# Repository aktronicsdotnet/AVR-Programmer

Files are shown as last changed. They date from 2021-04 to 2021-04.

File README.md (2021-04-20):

<b>
AVR Programmer based on USBASP that can be used as a Arduino shield or standalone
</b>
<br><br>
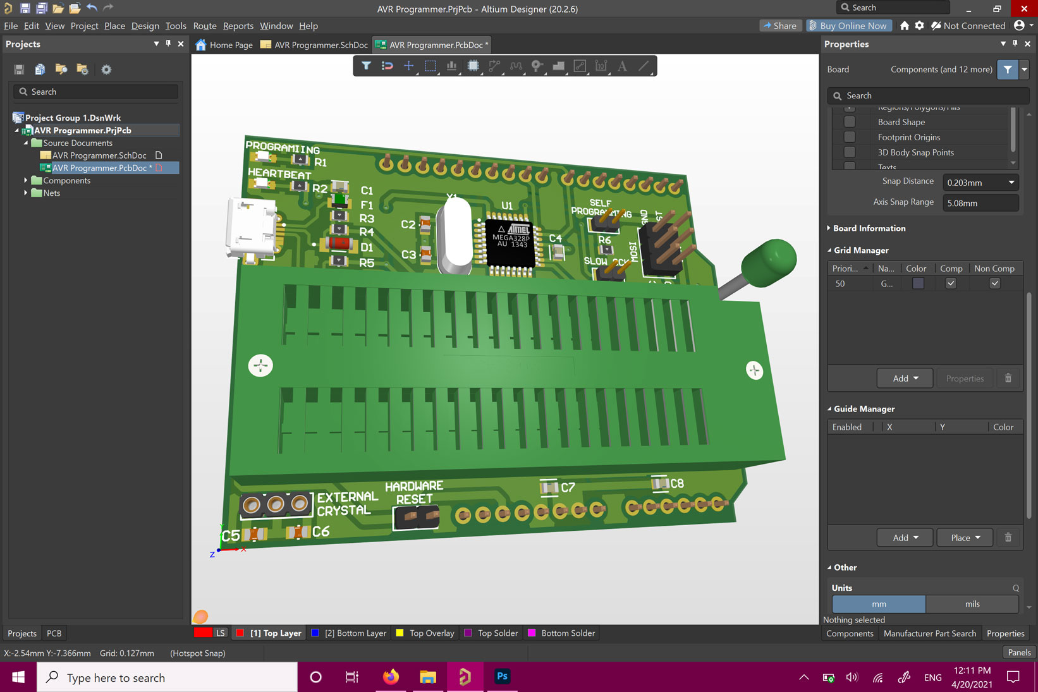
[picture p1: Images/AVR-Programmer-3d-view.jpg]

<br><br>

<b>
What is AVR-Programmer?
</b><br>
Everyone knows that you can use Arduino UNO as a programmer for other AVR MCUs that are supported by Arduino IDE and I'm sure at some point you have heard about USBASP if you have worked with Arduino and AVR MCUs... AVR-Programmer is a combination of these two things and can be used as both of them depending on how you assemble it.
<br><br>

<b>
How to use AVR-Programmer as a shield for Arduino UNO?
</b><br>
This is the easier version; all you need to do is to solder Arduino pin headers (D0 to D13 and power headers) and the ZIF socket. Bam... you are done and now you can upload the AVR as ISP sketch in Arduino ide, plug the shield and use it to program different type of AVR MCUs. Optionally you can populate the R1 and R2 with their respected LEDS to be able to visually see the progress of programming your MCUs and perhaps populate the external crystal socket, C5 and C6 to use external clocks with your MCUs.
<br><br>

<b>
What can I do with AVR-Programmer as a shield for Arduino UNO?
</b><br>
Well together with an Arduino Uno you can burn the bootloader or even program any AVR MCUs that are supported by Arduino IDE. (Officially or with addon packages)
<br><br>

<b>
How to use AVR-Programmer as standalone USBASP?
</b><br>
To my understanding you need to have one AVR programmer or at least an Arduino UNO to be able to programmer the ATMega8 or ATMega88 on the board as a USBASP first. If you have access to a AVR programmer you can use the 6 pin ISP header on the board to program the main MCU, in this case you can skip the Arduino headers completely but if you want to use an Arduino Uno you will need those headers so you will probably need to solder the whole board. Close the Self Programming jumper when you are programming the on board ATMega MCU, this jumper will connect the U1 RST pin to the rest of Reset pins on the board to be able to put 1 in programming mode just when we need it.
<br><br>

<b>
What can I do with AVR-Programmer as standalone USBASP?
</b><br>
Well in this case you can use the Micro USB port to burn the bootloader or program any AVR MCUs that are supported by USBASP. You can directly plug it on Arduino UNO to burn the bootloader or program them, in this case close the Hardware Reset jumper or you can use this board to program other Arduino boards with the 6 pin ISP connector with the standard pinout. 
<br><br>

<b>
What are those jumpers for?
</b><br>
I think it's really self explanatory but there are 3 jumpers on this board. One is called "Self Programming" this jumper is used to program the on board MCU and its job is to connect U1 RST pin to the rest of RESET pins. Another one is called "Slow SCK" this is used to slow down the clock of SCK pin and the last one is called "Hardware Reset" this is used to connect Arduino UNO's RST Pin to the rest of RESET pins to be able to put Arduino UNO boards into programming mode.
<br><br>

<b>
How can I use this?
</b><br>
First you need to send the Gerber files from Gerber X2 folder to your fav PCB manufacturer and wait until they make the PCB for you and the you need to buy the necessary components according to the bill of material and when everything arrived careful solder them to the PCB and use it.
<br><br>

<b>
For more advanced users...
</b><br>
For more advanced users, I've left the original design so you can change anything you want. This board was designed by Altium Designer V20.
<br><br>

<b>
How can you find me?
</b><br>
I will leave my Instagram on this GitHub just in case you needed to contact me for any reason... Instagram @ skopusdotorg
<br><br>

<b>
More pictures?
</b><br>
Here are some more pictures for your visual pleasure I guess...
<br>
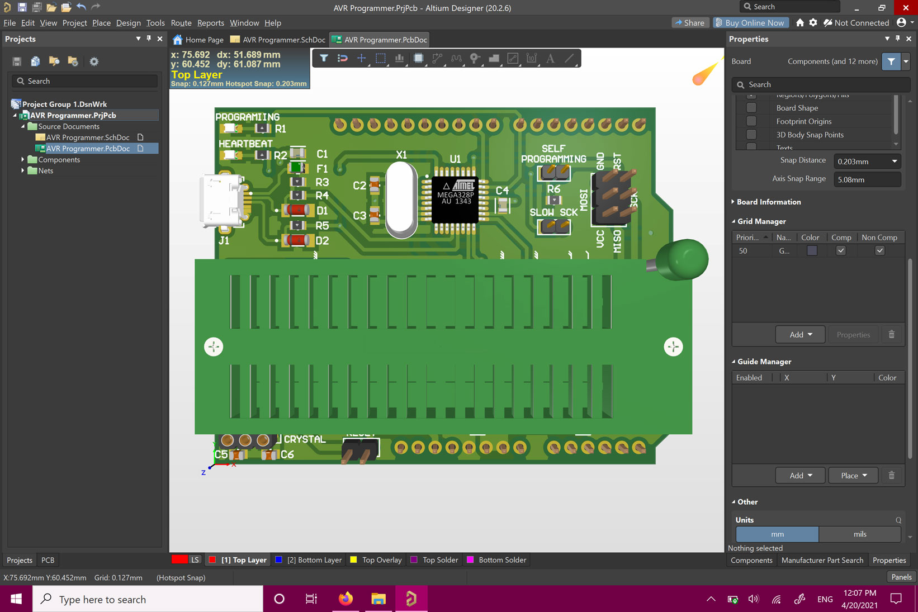
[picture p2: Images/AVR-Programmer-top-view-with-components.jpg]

<br>
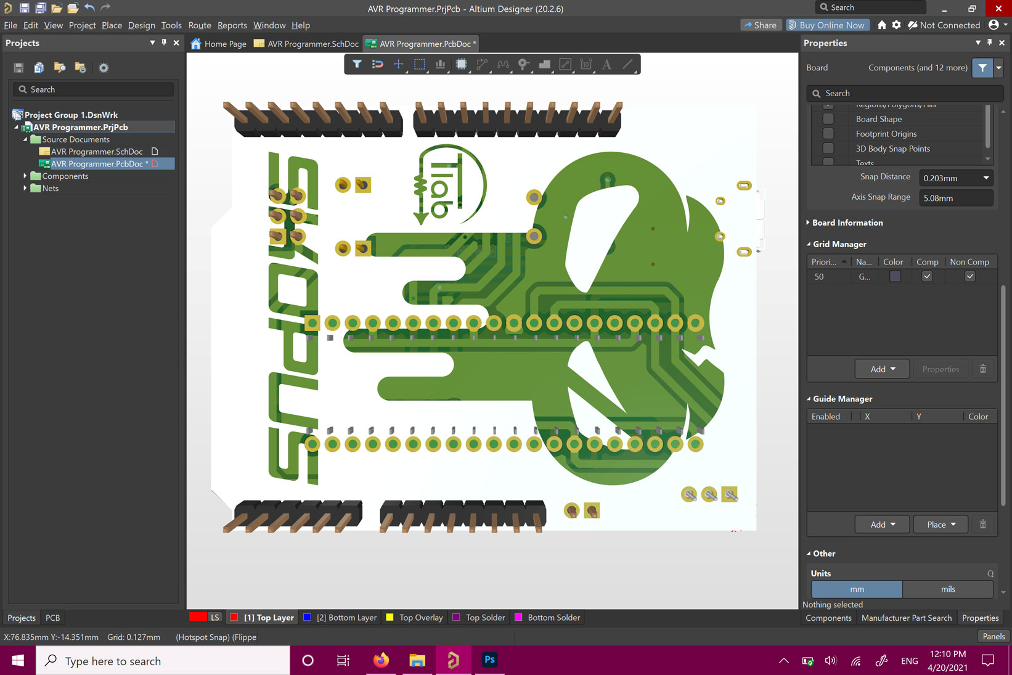
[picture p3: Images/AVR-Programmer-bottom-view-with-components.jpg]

<br>
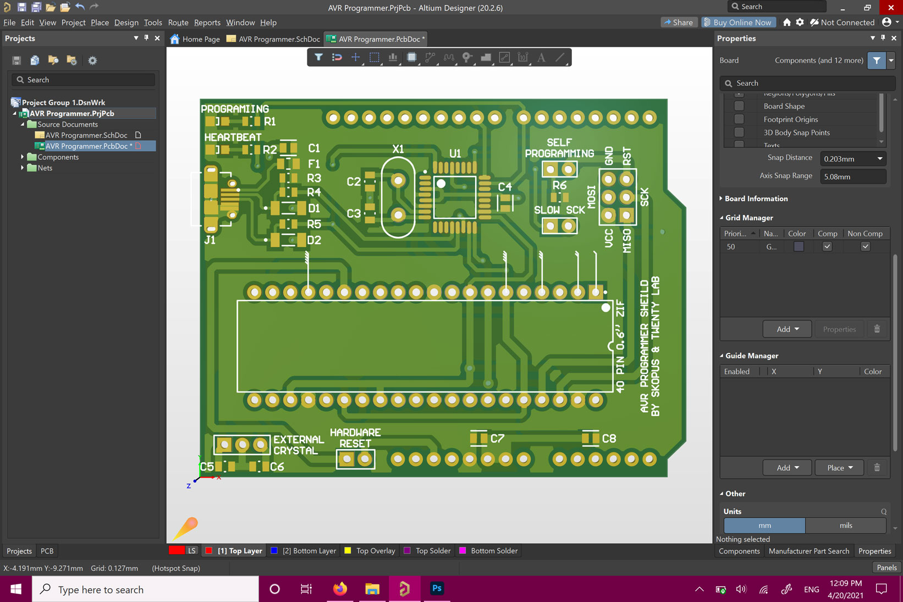
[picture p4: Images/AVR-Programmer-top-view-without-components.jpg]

<br>
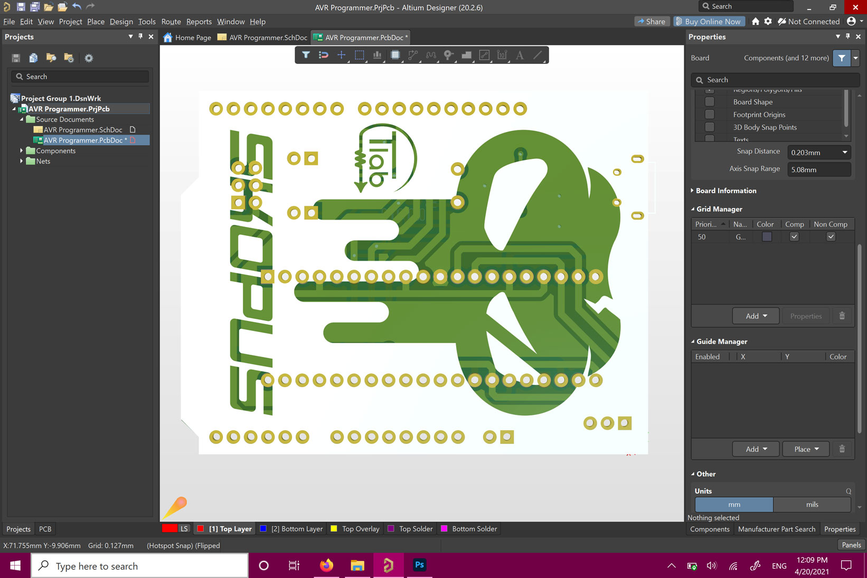
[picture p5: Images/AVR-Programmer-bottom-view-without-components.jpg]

<br>

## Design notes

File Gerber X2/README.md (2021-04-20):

Upload the "Gerber for AVR Programmer.zip" file to your fav PCB manufacturer website...

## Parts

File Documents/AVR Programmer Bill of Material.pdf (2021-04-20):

Altium Limited Confidential | 4/20/2021 | Page 1
Bill of Materials | Bill of Materials for PCB Document [AVR Programmer.PcbDoc]
Source Data From: | AVR Programmer.PcbDoc
Project: | | Free Documents
Variant: | | None
Creation Date: 4/20/2021 | 12:51 PM
Print Date: | 20-Apr-21 | 12:51:59 PM
Footprint | Comment | LibRef | Designator | Description | Quantity
FP-C0805C-DN-MFG
| 10UF | CMP-2007-
00235-2
C1, C7 | CAP CER 1000PF 50V C0G/NP0 0805 | 2
FP-CC0805-
0_85-MFG
| 22PF | CMP-2100-
03606-3
C2, C3, C5, C6 | CAP CER 0.1UF 50V X7R 0805 | 4
FP-C0805C-DN-MFG
| 100NF | CMP-2007-
00403-2
C4, C8 | CAP CER 680PF 50V X7R 0805 | 2
FP-6_560-
5005_01-4-
| 3.6V | CMP-02541-
000010-1
D1, D2 | DIODE ZENER 5.1V 500MW SOD80 | 2
FP-0805L-MFG
| 0805L050WR | CMP-08606-
000023-1
F1 | PTC RESET FUSE 6V 500MA 0805 | 1
MOLX-47589-
0001_V
| 47589-0001 | CMP-2000-
05610-1
| | | J1 | Right Angle Female Type AB Micro USB
Connector, 30 V, 1.8 A, -30 to 85 degC,

1
FP-M22-
2510205-MFG
| SIL2 | CMP-15831-
000005-1
J2, J3 | CONN HEADER VERT 2POS 2MM | 2
61300621121 | 61300621121 | CMP-1502-
01072-1
| | | J4 | THT Vertical Pin Header WR-PHD, Pitch
2.54 mm, Dual Row, 6 pins

1
61300811121 | D0-D7 | CMP-1502-
01076-1
| | | J4 | THT Vertical Pin Header WR-PHD, Pitch
2.54 mm, Single Row, 8 pins

1
61301011121 | D8-D13 | CMP-1502-
01082-1
| | | J5 | THT Vertical Pin Header WR-PHD, Pitch
2.54 mm, Single Row, 10 pins

1
61300611121 | A0-A6 | CMP-1502-
01070-1
| | | J6 | THT Vertical Pin Header WR-PHD, Pitch
2.54 mm, Single Row, 6 pins

1
61300811121 | POWER | CMP-1502-
01076-1
| | | J7 | THT Vertical Pin Header WR-PHD, Pitch
2.54 mm, Single Row, 8 pins

1
61300311121 | 61300311121 | CMP-1502-
01062-1
| | | J8 | THT Vertical Pin Header WR-PHD, Pitch
2.54 mm, Single Row, 3 pins

1
61300211121 | 61300211121 | CMP-1712-
00002-4
| | | J9 | THT Vertical Pin Header WR-PHD, Pitch
2.54 mm, Single Row, 2 pins

1
0805_A | | CMP-1426-
00010-1
| | | LED1 | SMD mono-color Chip LED, WL-SMCW,
Super Red

1
0805_A | 150080SS75000 | CMP-1426-
00010-1
| | | LED2 | SMD mono-color Chip LED, WL-SMCW,
Super Red

1
FP-CRCW0805-
| 1KΩ | CMP-2001-
04979-2
| | | R1, R2 | RES Thick Film, 68Ω, 1%, 0.125W,
100ppm/°C, 0805

2
FP-CRCW0805-
| 2.2KΩ | CMP-2001-
04979-2
| | | R3 | RES Thick Film, 68Ω, 1%, 0.125W,
100ppm/°C, 0805

1
FP-CRCW0805-
| 68Ω | CMP-2001-
04979-2
| | | R4, R5 | RES Thick Film, 68Ω, 1%, 0.125W,
100ppm/°C, 0805, RES Thick Film, 16kΩ,

2
FP-CRCW0805-
| 10KΩ | CMP-2001-
04979-2
| | | R6 | RES Thick Film, 68Ω, 1%, 0.125W,
100ppm/°C, 0805

1
40P6 | 40 Pin DIP 0.6"
ZIF Socket

CMP-0095-
00014-2
| | | S1 | 8-bit AVR Microcontroller, 32KB Flash,
1KB EEPROM, 2KB SRAM, 40-pin PDIP,

1
32A_N | ATmega8A-AU | CMP-0095-
00219-2
| | | U1 | 8-bit AVR Microcontroller, 2.7-5.5V,
16MHz, 8KB Flash, 512 Bytes EEPROM,

1
FOX-FOXSLF-2_V
| 12MH | CMP-1749-
00004-1
| | | X1 | Resistance Weld Thru-Hole Crystal, 12
MHz, +/-30 ppm, -20 to 70 degC, 2-Pin

1
32
Approved | | Notes

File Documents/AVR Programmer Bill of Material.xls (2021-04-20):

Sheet: BOM Report
Bill of Materials |  |  | Bill of Materials for PCB Document [AVR Programmer.PcbDoc]
Source Data From: |  | AVR Programmer.PcbDoc
Project: |  | Free Documents
Variant: |  | None
Creation Date: | 4/20/2021 | 12:52 PM
Print Date: | 2021-04-20 | 12:52:44
Footprint | Comment | LibRef | Designator | Description | Quantity
FP-C0805C-DN-MFG | 10UF | CMP-2007-00235-2 | C1, C7 | CAP CER 1000PF 50V C0G/NP0 0805 | 2
FP-CC0805-0_85-MFG | 22PF | CMP-2100-03606-3 | C2, C3, C5, C6 | CAP CER 0.1UF 50V X7R 0805 | 4
FP-C0805C-DN-MFG | 100NF | CMP-2007-00403-2 | C4, C8 | CAP CER 680PF 50V X7R 0805 | 2
FP-6_560-5005_01-4-MFG | 3.6V | CMP-02541-000010-1 | D1, D2 | DIODE ZENER 5.1V 500MW SOD80 | 2
FP-0805L-MFG | 0805L050WR | CMP-08606-000023-1 | F1 | PTC RESET FUSE 6V 500MA 0805 | 1
MOLX-47589-0001_V | 47589-0001 | CMP-2000-05610-1 | J1 | Right Angle Female Type AB Micro USB Connector, 30 V, 1.8 A, -30 to 85 degC, RoHS, Tape and Reel | 1
FP-M22-2510205-MFG | SIL2 | CMP-15831-000005-1 | J2, J3 | CONN HEADER VERT 2POS 2MM | 2
61300621121 | 61300621121 | CMP-1502-01072-1 | J4 | THT Vertical Pin Header WR-PHD, Pitch 2.54 mm, Dual Row, 6 pins | 1
61300811121 | D0-D7 | CMP-1502-01076-1 | J4 | THT Vertical Pin Header WR-PHD, Pitch 2.54 mm, Single Row, 8 pins | 1
61301011121 | D8-D13 | CMP-1502-01082-1 | J5 | THT Vertical Pin Header WR-PHD, Pitch 2.54 mm, Single Row, 10 pins | 1
61300611121 | A0-A6 | CMP-1502-01070-1 | J6 | THT Vertical Pin Header WR-PHD, Pitch 2.54 mm, Single Row, 6 pins | 1
61300811121 | POWER | CMP-1502-01076-1 | J7 | THT Vertical Pin Header WR-PHD, Pitch 2.54 mm, Single Row, 8 pins | 1
61300311121 | 61300311121 | CMP-1502-01062-1 | J8 | THT Vertical Pin Header WR-PHD, Pitch 2.54 mm, Single Row, 3 pins | 1
61300211121 | 61300211121 | CMP-1712-00002-4 | J9 | THT Vertical Pin Header WR-PHD, Pitch 2.54 mm, Single Row, 2 pins | 1
0805_A |  | CMP-1426-00010-1 | LED1 | SMD mono-color Chip LED, WL-SMCW, Super Red | 1
0805_A | 150080SS75000 | CMP-1426-00010-1 | LED2 | SMD mono-color Chip LED, WL-SMCW, Super Red | 1
FP-CRCW0805-e3-IPC_C | 1KΩ | CMP-2001-04979-2 | R1, R2 | RES Thick Film, 68Ω, 1%, 0.125W, 100ppm/°C, 0805 | 2
FP-CRCW0805-e3-IPC_C | 2.2KΩ | CMP-2001-04979-2 | R3 | RES Thick Film, 68Ω, 1%, 0.125W, 100ppm/°C, 0805 | 1
FP-CRCW0805-e3-IPC_C | 68Ω | CMP-2001-04979-2 | R4, R5 | RES Thick Film, 68Ω, 1%, 0.125W, 100ppm/°C, 0805, RES Thick Film, 16kΩ, 1%, 0.125W, 100ppm/°C, 0805 | 2
FP-CRCW0805-e3-IPC_C | 10KΩ | CMP-2001-04979-2 | R6 | RES Thick Film, 68Ω, 1%, 0.125W, 100ppm/°C, 0805 | 1
40P6 | 40 Pin DIP 0.6" ZIF Socket | CMP-0095-00014-2 | S1 | 8-bit AVR Microcontroller, 32KB Flash, 1KB EEPROM, 2KB SRAM, 40-pin PDIP, Industrial Grade (-40°C to 85°C) | 1
32A_N | ATmega8A-AU | CMP-0095-00219-2 | U1 | 8-bit AVR Microcontroller, 2.7-5.5V, 16MHz, 8KB Flash, 512 Bytes EEPROM, 1KB SRAM, 32-pin TQFP, Industrial Grade (-40°C to 85°C) | 1
FOX-FOXSLF-2_V | 12MH | CMP-1749-00004-1 | X1 | Resistance Weld Thru-Hole Crystal, 12 MHz, +/-30 ppm, -20 to 70 degC, 2-Pin THD, RoHS, Bulk | 1
 |  |  |  |  | 32
Approved |  | Notes

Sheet: Project Information
Project Full Path | Free Documents
Project Filename | Free Documents
Variant Name | None
Data-Source Filename | AVR Programmer.PcbDoc
Data-Source Full Path | C:\Users\khaza\Documents\Proteus\KaraPCB\Others\Unrelated Stuff\AVR Programmer\AVR Programmer.PcbDoc
Title | Bill of Materials for PCB Document [AVR Programmer.PcbDoc]
Total Quantity | 32
Report Time | 12:52 PM
Report Date | 4/20/2021
Report Date & Tine | 4/20/2021 12:52 PM
Output Name | Bill of Materials
Output Type | BOM_PartType
Output Generator Name | BOM
Output Generator Description | Bill of Materials

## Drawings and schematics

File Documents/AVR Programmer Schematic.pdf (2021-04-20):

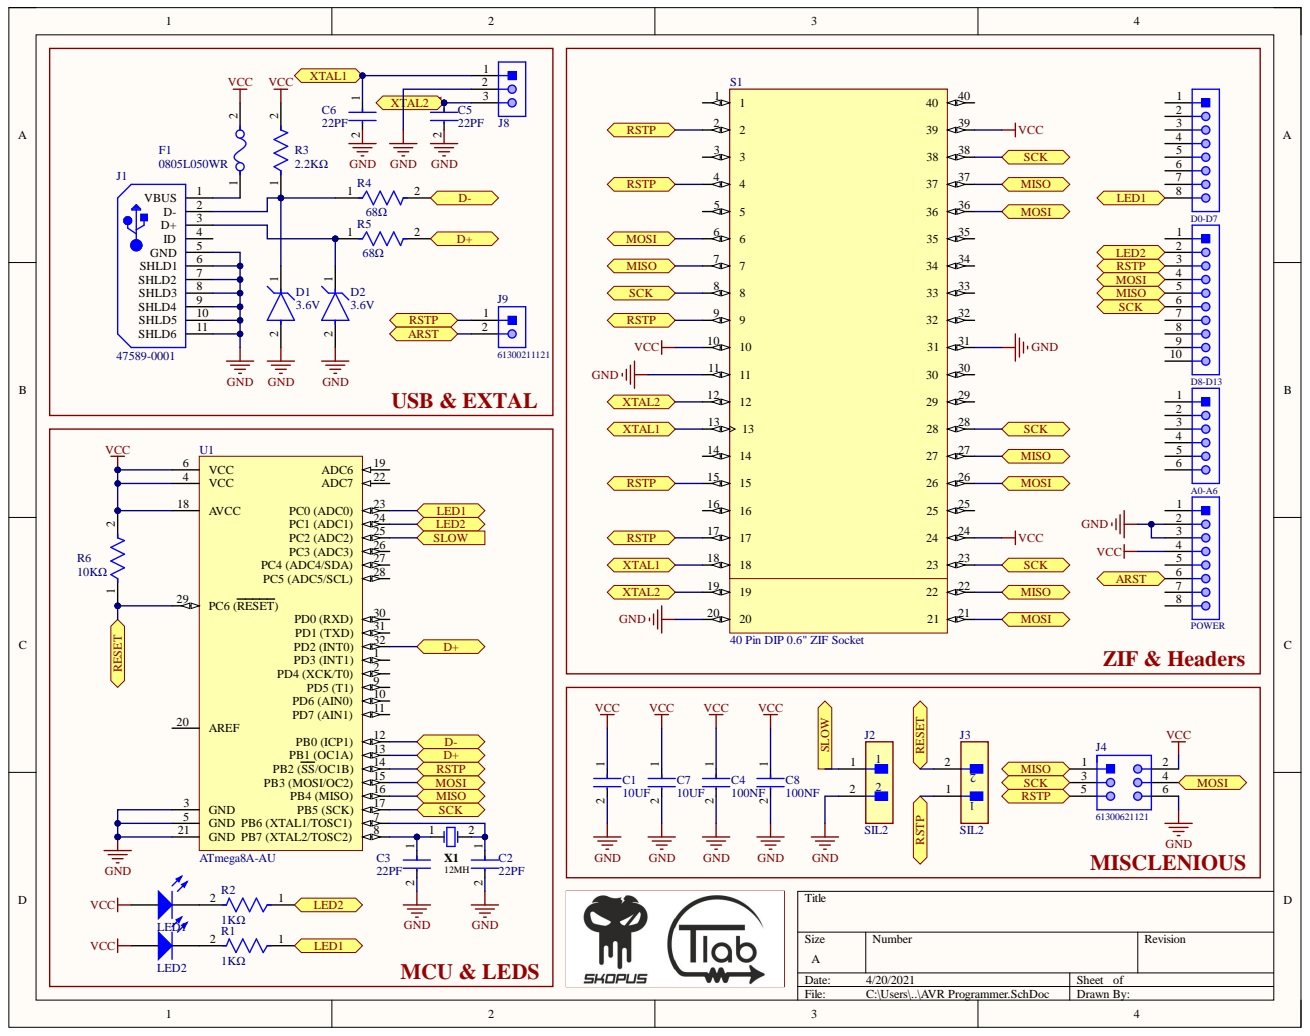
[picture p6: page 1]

40 Pin DIP 0.6" ZIF Socket
